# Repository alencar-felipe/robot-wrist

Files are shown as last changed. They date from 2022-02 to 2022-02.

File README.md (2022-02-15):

# robot-wrist

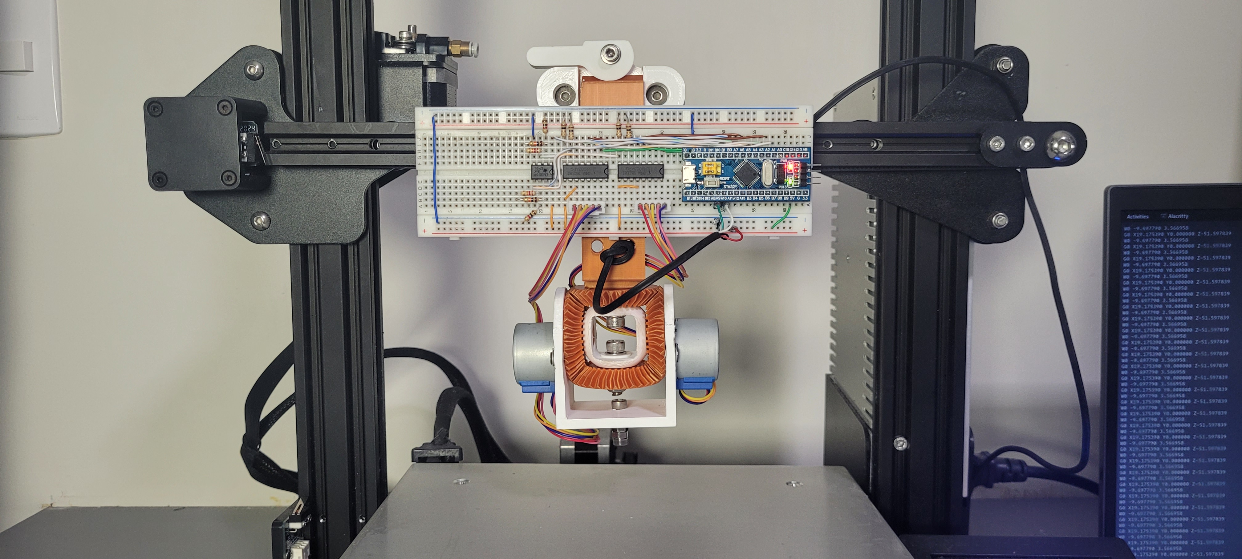
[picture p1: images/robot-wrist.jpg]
robot-wrist


## About

The robot-wrist is a robot that (tries to) mimic the movement of a human wrist
(and forearm). In addition to developing the robot itself, it also was 
integrated with a 3D printer and a PS4 controller to demonstrate a usage case.

Furthermore, it is the final project of the discipline of Microprocessed Systems
taught by Professor Ricardo Jardel Nunes da Silveira from the Federal University
of Ceará (UFC).

## Authors

- Dariel Bezerra de Sousa (495208)
- Felipe Paiva Alencar (494543).

## Summary
- [Controller](controller/)
- [Firmware](firmware/)
- [OpenSCAD (3D Model)](openscad/)
- [Proteus (Schematic)](proteus)

## Video

Video (https://www.youtube.com/watch?v=ubxL-wMxCd8 "Projeto Final da Disciplina de POO")

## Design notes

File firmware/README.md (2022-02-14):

# Firmware

## About

This firmware runs on an [STM32F103C6T6](https://www.st.com/en/microcontrollers-microprocessors/stm32f103c6.html).
The main highlight of this code is that it does not use the Hardware 
Abstraction Layer (HAL) provided by the STM32CubeMX software. Therefore, we
configured all the registers manually. (We also made the linker and startup code
from scratch)

The code listens for incoming gcode commands from the USART and, when the robot 
receives a command, it takes the necessary action: move the motors, change the
coordinate origin or measure current.

Peripherals used: ADC1, ADC2, GPIO, TIM3, USART1. 

## Custom Gcode
### W0: Move
Performs a movement.

#### Usage
```
W0 [rotation] [arm]
```

#### Parameters
- [rotation]: rotation angle in degrees
- [arm]: arm angle in degrees

#### Example
```
W0 180.0 0.0
```

### W1: Set position
Set the current position to the values specified. (Does not move the motors)

#### Usage
```
W1 [rotation] [arm]
```
#### Parameters
- [rotation]: rotation angle in degrees
- [arm]: arm angle in degrees

#### Example
```
W1 0.0 0.0
```

### W2: Get electric currents value
Gets currents of both motors in amperes.

#### Usage
```
W2
```

#### Example

```
W2
0.141 0.136
```

## Build

```
$ make clean && make build
```

## Flash

```
$ make flash
```
## Debug

```
$ openocd -f stlink_bluepill.cfg &
$ arm-none-eabi-gdb build/robot-wrist.elf
(gdb) target remote :3333
```

Reset: ```monitor reset halt```

## References

- https://www.st.com/resource/en/reference_manual/cd00171190-stm32f101xx-stm32f102xx-stm32f103xx-stm32f105xx-and-stm32f107xx-advanced-arm-based-32-bit-mcus-stmicroelec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
- https://mensi.ch/blog/articles/bare-metal-c-programming-the-blue-pill-part-1
- https://github.com/fcayci/stm32f1-bare-metal
- https://vivonomicon.com/2020/06/28/bare-metal-stm32-programming-part-10-uart-communication/
- https://stackoverflow.com/questions/22317477/setting-up-heap-in-memory-for-arm-embedded-system
- https://github.com/IDWizard/uln2003

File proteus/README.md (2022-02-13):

# Proteus

An STM32 is the main microcontroller. This MCU controls two stepper motor
drivers, which, in turn, controls two stepper motors. Furthermore, an ammeter
accompanies each motor driver.

## Material
 - 1x STM32F103C6 (MCU)
 - 2x 28BYJ-48 (Stepper Motor)
 - 2x ULN2003A (Stepper Motor Driver)
 - 1x LM358 (OP-AMP)

## Schematic

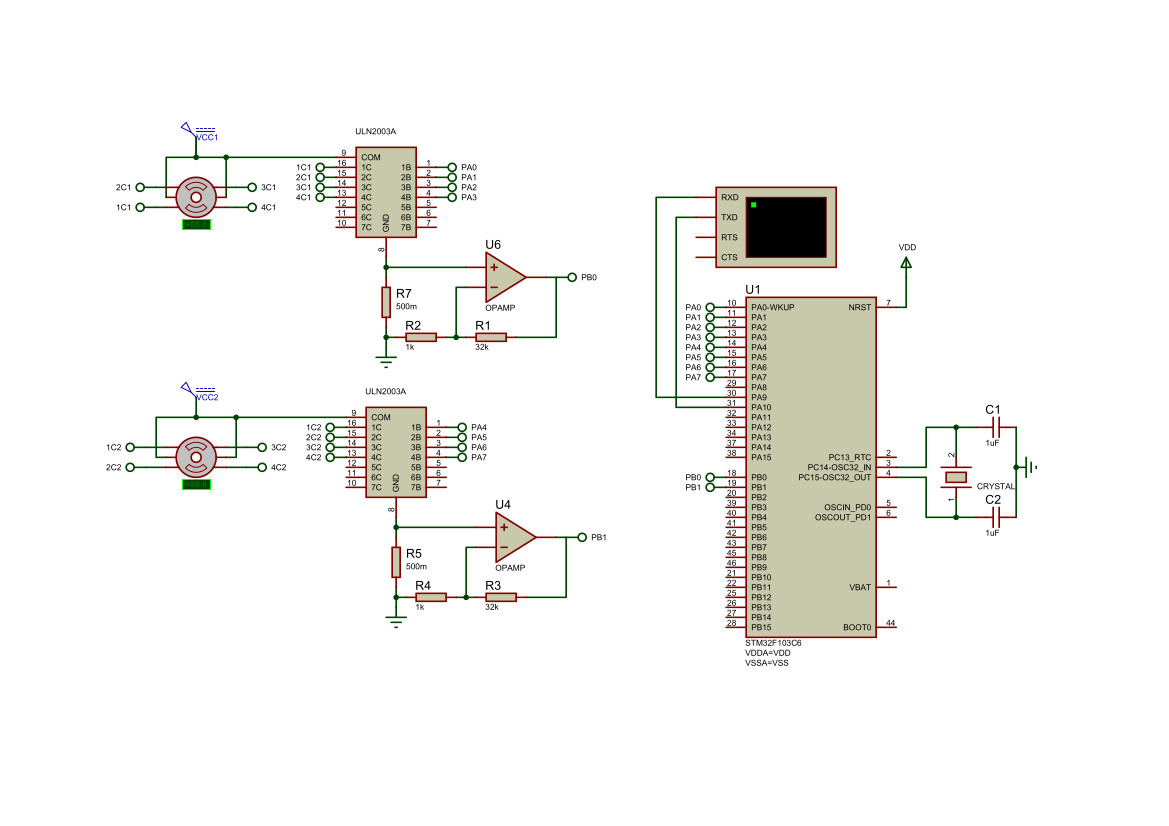
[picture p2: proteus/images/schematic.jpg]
Schematic


## Protoboard

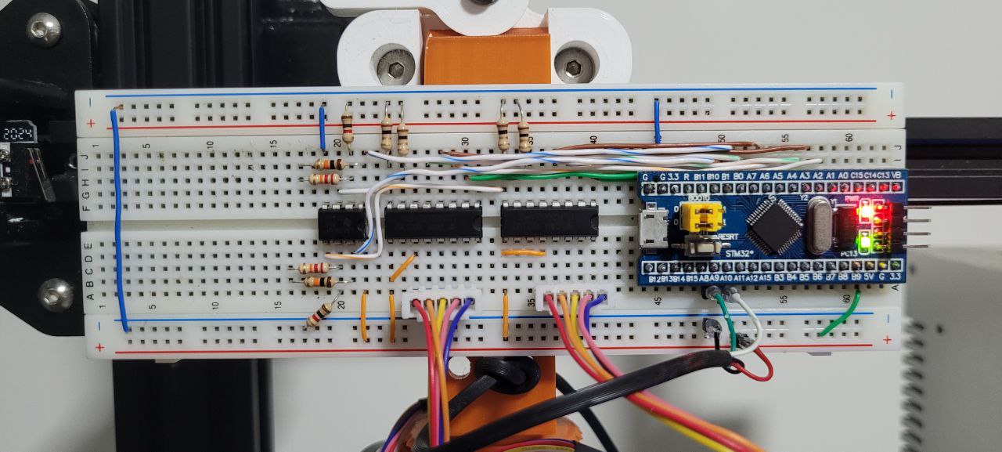
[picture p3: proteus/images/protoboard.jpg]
Protoboard


## Resources
- https://www.st.com/resource/en/datasheet/stm32f103c6.pdf
- https://www.mouser.com/datasheet/2/758/stepd-01-data-sheet-1143075.pdf
- https://www.st.com/resource/en/datasheet/uln2001.pdf
- https://www.ti.com/lit/ds/symlink/lm158-n.pdf
- https://www.filipeflop.com/wp-content/uploads/2017/07/450xN-4-2.jpg

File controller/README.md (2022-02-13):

# Controller

Simple Python script to control a 3D printer (running 
[marlin](https://marlinfw.org/meta/gcode/)) and the robot-wrist via a PS4
cotroller.

## Button Mapping

PS4 Controller

- Button 6 (L2): Printer Z axis up

- Button 7 (R2): Printer Z axis down

- Button 10 (L3):
    - X axis: Printer X axis
    - Y axis: Printer Y axis

- Button 11 (R3):
    - X axis: robot-wrist rotation
    - Y axis: robot-wrist arm

## Run

```
pip install -r requirements.txt
python3 controller.py <robot-wrist-serial-port> <marlin-serial-port>
```

## Resources
- https://marlinfw.org/meta/gcode/
- https://pypi.org/project/pyPS4Controller/
- https://forum.unity.com/proxy.php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

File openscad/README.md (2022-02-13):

# OpenSCAD

3D model for a robot that mimics the movement of a human wrist (and forearm) 
with a spur-gear differential. This 3D model, basically, is a scaled down version
of the model made by: [Tiago Charters de Azevedo](youtube.com/watch?v=JI7P6k4t3Ws)

## Render

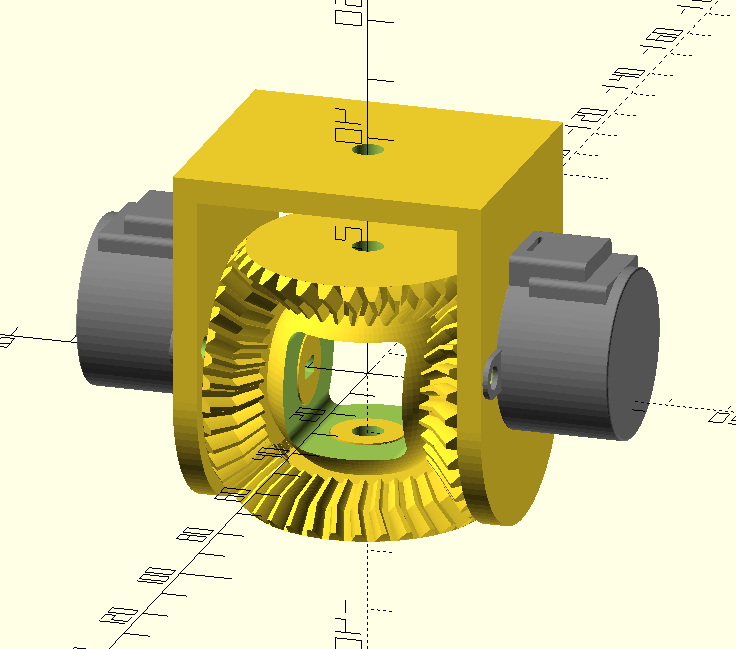
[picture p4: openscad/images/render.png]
OpenSCAD Render


[3D Visualization](robot-wrist.stl)

## 3D Printed

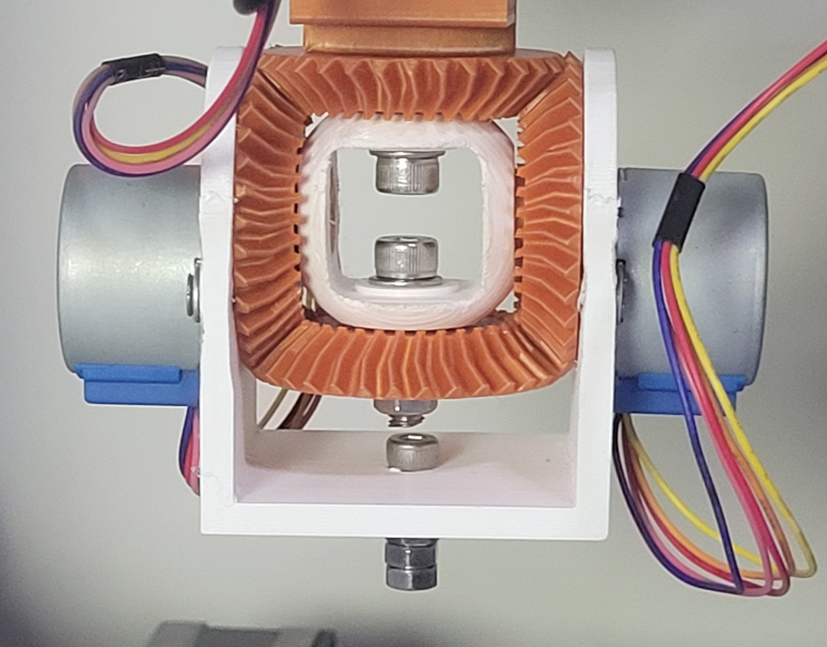
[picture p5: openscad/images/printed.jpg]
3D Printed


## Resources
- https://www.youtube.com/watch?v=JI7P6k4t3Ws
- https://www.youmagine.com/designs/improved-robot-arm-with-a-3d-printed-differential-wrist-3-25
- https://github.com/chrisspen/gears

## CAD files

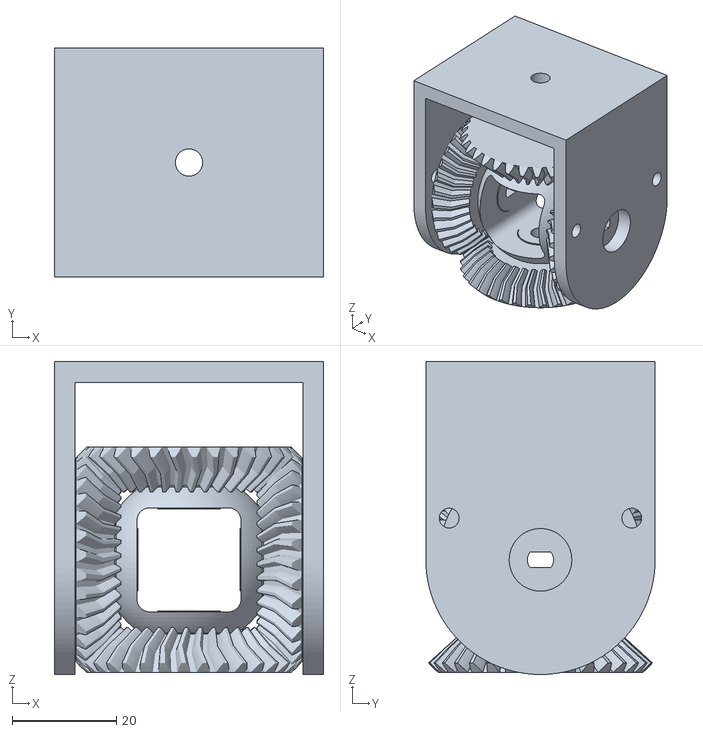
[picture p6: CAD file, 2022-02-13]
openscad/robot-wrist.stl
51.7 x 44.0 x 60.0

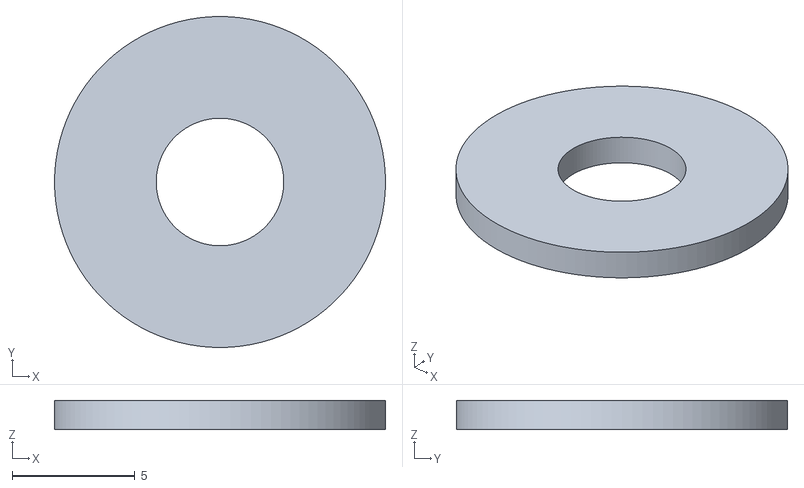
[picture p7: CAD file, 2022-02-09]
openscad/whasher.stl
13.5 x 13.5 x 1.20

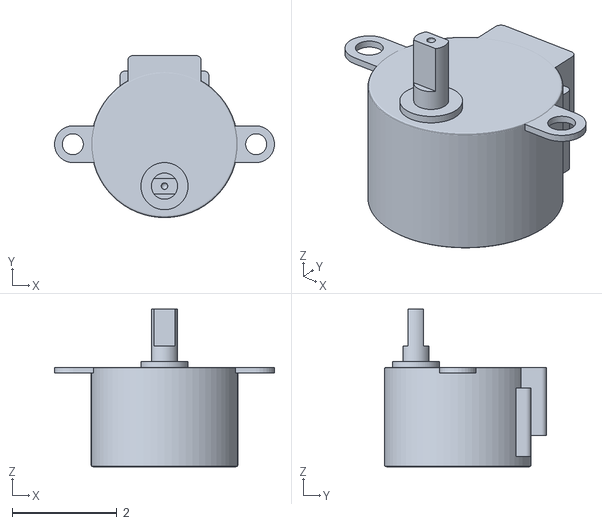
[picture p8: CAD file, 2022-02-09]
openscad/stepper.stl
4.20 x 3.10 x 3.01

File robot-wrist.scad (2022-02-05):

include <gears.scad>
include <nema17.scad>
include <../utils/threads.scad>

gear2_bolt_hex_d=12.8;
gear2_bolt_sink=4;



h=5;

modul=1.5;
top_tooth_number=53;
rt_tooth_number=top_tooth_number;
small_tooth_number=11;
a=modul*(2+top_tooth_number);

b=modul*(2+rt_tooth_number);
aa=modul*(2+small_tooth_number);

db=-aa/2+2*(modul+modul/6);

c=a;
rtube=2.54*10;
echo(c);
tol=.4;

smallgearoffset=.6;


////////////////////////////////////////////////////////////
nema=0;
module big_gear(modul=1.5){
	bevel_herringbone_gear(
	    modul=modul,
	    tooth_number=top_tooth_number,
	    partial_cone_angle=45,
	    tooth_width=10,
	    bore=4,
	    pressure_angle=20,
	    helix_angle=-20);
    }


module top_gear(modul=1.5,m=11){
    difference(){
	union(){
	    bevel_herringbone_gear(
		modul=modul,
		tooth_number=top_tooth_number,
		partial_cone_angle=45,
		tooth_width=10,
		bore=4,
		pressure_angle=20,
		helix_angle=20);

	    translate([0,0,-7]){
	    cylinder(h=(10+2*modul)*sin(45)+7,r=16,center=false);
	    cylinder(h=7,r1=a/2-2*modul-7,r2=a/2-sqrt(2)*modul,center=false);
	}
	    
    }
    
    translate([0,0,(10+2*modul)*sin(45)-7])
    poly_cylinder(h=7+.5,r=11);
    
    translate([0,0,-3.5])	
    poly_cylinder(h=7+.5,r=11,center=true);
    
    poly_cylinder(h=100,r=11-.32,center=true);


    //holes
    for(i=[0:m-1]){
	rotate([0,0,i*360/m])
	translate([0,a/3.5,0])
	poly_cylinder(h=20,r=4,center=true);}
}
}

module bottom_gear(modul=1.5,m=11){
    difference(){
	union(){
	    bevel_herringbone_gear(
		modul=modul,
		tooth_number=top_tooth_number,
		partial_cone_angle=45,
		tooth_width=10,
		bore=4,
		pressure_angle=20,
		helix_angle=20);
	    
	    translate([0,0,-7]){
		cylinder(h=(10+2*modul)*sin(45)+7,r=16,center=false);
	    }

	    translate([0,0,-7]){
	    cylinder(h=(10+2*modul)*sin(45)+7,r=16,center=false);
	    cylinder(h=7,r1=a/2-2*modul-7,r2=a/2-sqrt(2)*modul,center=false);
	}
    }
    
    translate([0,0,(10+2*modul)*sin(45)-7])
    poly_cylinder(h=7+.5,r=11);
    
    translate([0,0,-3.5])	
    poly_cylinder(h=7+.5,r=11,center=true);
    
    poly_cylinder(h=100,r=11-.32,center=true);
    
    //holes
    for(i=[0:m-1]){
	rotate([0,0,i*360/m])
	translate([0,a/3.5,0])
	poly_cylinder(h=20,r=4,center=true);}
}

height=50;
translate([0,0,-height-.01])
base(height=height,screws=true);
}

module lr_big_gear(modul=1.5,m=11){
    difference(){
	union(){
	    difference(){
		big_gear();
		translate([0,0,3.5+.4])
		poly_cylinder(h=7,r=11,center=true);
		
		poly_cylinder(h=100,r=11-.32,center=true);}
	    
	    translate([0,0,-10])
	    difference(){
		herringbone_gear(
		    modul=modul,
		    tooth_number=rt_tooth_number,
		    width=10,
		    bore=2*(11-.32),
		    pressure_angle=20,
		    helix_angle=30,
		    optimized=false);
		
		translate([0,0,3.5])
		poly_cylinder(h=7,r=11,center=true);}}

        //holes
    for(i=[0:m-1]){
	rotate([0,0,i*360/m])
	translate([0,a/3.5,0])
	poly_cylinder(h=20,r=4,center=true);}
}
}

module small_gear(modul=1.5){
    translate([0,a/2+smallgearoffset,-7]){
	rotate([0,0,-9])
	union(){
	    herringbone_gear(
		modul=modul,
		tooth_number=small_tooth_number,
		width=10,
		bore=5,
		pressure_angle=20,
		helix_angle=-30,
		optimized=false);
	}
	
	translate([0,0,-10])
	difference(){
	    cylinder(h=10,r=aa/2);
	    poly_cylinder(h=20,r=2.5,center=true);
	    
	    translate([0,0,5])
	    rotate([0,90,0])
	    poly_cylinder(h=20,r=1.5,center=true);
	    
	    translate([-5,0,5])
	    cube([2.8,5.6,10+.1],center=true);
	}
    }
	
}



module show(){
    translate([0,0,a/2])
    rotate([0,180,0])
    top_gear(modul=modul);
    
    translate([-a/2,0,0])
    rotate([0,90,0])
    lr_big_gear();
    
    union(){
	translate([a/2,0,0])
	rotate([0,-90,])
	lr_big_gear();
	
	translate([a/2+3,0,db])
	rotate([-90+0,0,0])
	rotate([0,-90,0])
	small_gear();}
    
    middleU();
    
    translate([-a/2-10*cos(45)-10-1.6,0,0]) lateral();
    
    translate([-a/2-3,0,db])
    rotate([-90,0,180])
    rotate([0,-90,0])
    small_gear(modul);
    
    
    translate([a/2+10*cos(45)+10+1.6,0,0])    rotate([0,0,180])    lateral();

    if(nema==1){
	// NEMA
	translate([-a/2-20-7,0,-a/2+db])
	rotate([0,90,0])
	nema17();
	
	// NEMA
	rotate([0,0,180])
	translate([-a/2-20-7,0,-a/2+db])
	rotate([0,90,0])
	nema17();}
	
	translate([0,0,a/2+25])    arm1(height=50-15);

    translate([0,0,-a/2])
    bottom_gear(modul=modul);

//    translate([0,0,a/2+200])
//    nema17();
}

show();
    


module middleU(c=a-10/sin(45)-2*1.6){
    rsphere=.65*c;
    lcube=c-4*7-1;
    difference(){
	intersection(){
	    cube(c*[1,1,1],center=true);
	    sphere(r=rsphere);}
	
	cube([lcube,100,lcube],center=true);
	
	poly_cylinder(h=100,r=11-.32,center=true);
	rotate([0,90,0])
	poly_cylinder(h=100,r=11-.32,center=true);

	// bearing hole
	for(i=[0:3]){
	    rotate([0,360*i/4,0]){
		    translate([0,0,c/2-3]) 
		    poly_cylinder(h=8,r=11,center=true);
		    translate([0,0,c/2-2*7+2])
		    poly_cylinder(h=8,r=11,center=true);}}}
    
    intersection(){
	sphere(r=rsphere);
	union(){
	    translate([lcube/2,0,lcube/2])
	    difference(){
		rotate([0,90,90])
		cylinder(h=c,r=7/2,center=true);
		translate([-7/2,0,-7/2])
		rotate([0,90,90])
		cylinder(h=c+1,r=7/2,center=true);}
	    
	    translate([-lcube/2,0,lcube/2])
	    difference(){
		rotate([0,90,90])
		cylinder(h=c,r=7/2,center=true);
		translate([7/2,0,-7/2])
		rotate([0,90,90])
		cylinder(h=c+1,r=7/2,center=true);}

	    ////////////////////////////////////////////////////////////
	    
	    translate([-lcube/2,0,-lcube/2])
	    difference(){
		rotate([0,90,90])
		cylinder(h=c,r=7/2,center=true);
		translate([7/2,0,7/2])
		rotate([0,90,90])
		cylinder(h=c+1,r=7/2,center=true);}

	    translate([lcube/2,0,-lcube/2])
	    difference(){
		rotate([0,90,90])
		cylinder(h=c,r=7/2,center=true);
		
		translate([-7/2,0,7/2])
		rotate([0,90,90])
		cylinder(h=c+1,r=7/2,center=true);}
	    
	    
	}}
}


module base(radius=a/2-modul,height=110, screws=false){
//    height=110;
    difference(){
	union(){
	    cylinder(h=height,r=radius+h,center=false);

	    cylinder(h=10,r=radius+3*h,center=false);

	    translate([0,0,-h])
	    cylinder(h=h,r=radius+3*h+.5*h,center=false);
	}
	poly_cylinder(h=10*height,r=radius,center=true);    
    
	wheel_radius = radius+5*h;
	tyre_diameter = 4*h;
	
	translate([0,0,2*h])
	rotate_extrude(angle=360) {
	    translate([wheel_radius - tyre_diameter/2, 0])
            circle(d=tyre_diameter);}

	if (screws){
	    for(i=[0:6]){
		rotate([0,0,i*360/7])
		translate([0,radius+2.5*h,0]){
		    poly_cylinder(h=100,r=1.5,center=true);
		    translate([0,0,0])
		    poly_cylinder(h=h,r=4,center=true);}}}


    // for(i=[0:6]){
    // 	rotate([0,0,(i+1/4)*360/7])
    // 	translate([0,0,height/1.25]){
    // 	    rotate([0,90,0])
    // 	    poly_cylinder(h=rtube+2*h,r=1.5,center=false);}}

}}

module lateral(width=15){
    lm3=31/2;
    l=105;
    difference(){
	union(){
	    hull(){
		rotate([0,90,0])
		cylinder(h=width,r=a/2,center=true);

		translate([0,0,a/2+15])
		cube([width,a,.01],center=true);

		translate([0,0,-b/2+db])
		rotate([0,90,0])

		minkowski(){
		    cube([43.3-5,43.3-5,width/2],center=true);
		    cylinder(h=width/2,r=2.5,center=true);}
	    }

	}

//	translate([0,-a/4,a/2+10]) cube([a/1.5,14.5,1],center=true);
	
	translate([0,a/4,a/2]) cube([a/1.5,15,6.3],center=true);
	translate([0,-a/4,a/2]) cube([a/1.5,15,6.3],center=true);

	translate([0,a/4,a/2])
	poly_cylinder(h=50,r=4,center=true);
	translate([0,-a/4,a/2])
	poly_cylinder(h=50,r=4,center=true);

	translate([h+.01,0,-smallgearoffset]){
	    ////////////////////////////////////////////////////////////
	    translate([0,0,-b/2+db])
	    rotate([0,90,0]){
		translate([lm3,lm3,0])
		poly_cylinder(h=h,r=4,center=true);
		translate([-lm3,lm3,0])
		poly_cylinder(h=h,r=4,center=true);
		translate([lm3,-lm3,0])
		poly_cylinder(h=h,r=4,center=true);
		translate([-lm3,-lm3,0])
		poly_cylinder(h=h,r=4,center=true);
		// Big hole

		poly_cylinder(h=15,r=23/2+6-.8,center=true);}
	    
	    translate([0,0,-b/2+db-20])
	    cube([width,20,width],center=true);
	    ////////////////////////////////////////////////////////////
	
	translate([0,0,-b/2+db])
	rotate([0,90,0]){
	    translate([lm3,lm3,0])
	    poly_cylinder(h=2*l,r=1.5,center=true);
	    translate([-lm3,lm3,0])
	    poly_cylinder(h=2*l,r=1.5,center=true);
	    translate([lm3,-lm3,0])
	    poly_cylinder(h=2*l,r=1.5,center=true);
	    translate([-lm3,-lm3,0])
	    poly_cylinder(h=2*l,r=1.5,center=true);
	    // Big hole    
	    poly_cylinder(h=2*l,r=23/2,center=true);}}

	rotate([0,90,0])
	poly_cylinder(h=2*l,r=4,center=true);

	translate([gear2_bolt_sink,0,0])
	rotate([0,90,0])
	cylinder(r=.5*gear2_bolt_hex_d /cos(180/6),h=gear2_bolt_sink,$fn=6);



}

}

module arm1(height=165){
    lenght=a/2+10*cos(45)+10+1.6+7.5;
    echo(lenght);
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

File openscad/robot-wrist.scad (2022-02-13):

include <gears.scad>

$fn=100;

thk=4;
nop=0.01;
screw=5.2;
bear=12; //bearing horizontal
bear_c=0.2; //bearing clearance
arm_c=0.2; //arm clearance
insert=3.8;
stteper_hole=12;

// HELPERS =====================================//

module rounded_square(s, r) {
    k = s/2 - r;
    
	hull() {
		translate([k, k, 0])
        circle(r);
		translate([k, -k, 0])
        circle(r);
		translate([-k, -k, 0])
        circle(r);
		translate([-k, k, 0])
        circle(r);
	}
}

module half_cylinder(h, d) {
    intersection() {
        cylinder(h=h, d=d, center=true);
        translate([0, d/4, 0])
        cube([d, d/2, h], center=true);
    }
}

module axis(h, d, c) {
   intersection() {
        cylinder(h=h, d=d);
        cube([c, d, 2*h], center=true);
    }
} 

// STEPPER =====================================//

module stepper() {
    translate([0, 8, -19/2])
    scale(10)
    import("stepper.stl", convexity=3);
}

module steppers(dx) {
    color("grey")
    for(i = [-1, 1]) {
        translate([i*dx, 0, 0])
        rotate([90, 0, -i*90])
        stepper();
    }
}

// DICE ========================================//

module dice(in, out, d, f, bore) {
    difference() {
        intersection() {
            cube(out, center=true);
            sphere(d=d);
        }
        
        rotate([90, 0, 0])
        linear_extrude(out+nop, center=true)
        rounded_square(in, f);
        
        cylinder(out+nop, d=bore,
        center=true);
        
        rotate([0, 90, 0])
        cylinder(out+nop, d=bore,
        center=true);
    }
}

// ARM =========================================//

module arm(size, gear_x) {
    dx = (gear_x + thk/2 + arm_c);
    side_h = sqrt(pow(gear_x+10, 2) + pow(10/2, 2))+2;
   
    for(i = [-1, 1]) {
        translate([i*dx, 0, 0]) {
            difference() {
                union() {
                    rotate([-90, 0, 90])
                    half_cylinder(thk, size);
                    translate([0, 0, side_h/2])
                    cube([thk, size, side_h+nop],
                        center=true);
                }
                
                for(j = [-1, 1])
                translate([0, j*35/2, 8])
                rotate([0, 90, 0])
                cylinder(h=thk+nop, d=insert, center=true);
                
                rotate([0, 90, 0])
                cylinder(h=thk+nop, d=stteper_hole, 
                    center=true);
            }
            
        }
    }
    
    translate([0, 0, thk/2+side_h])
    difference() {
        cube([2*dx+thk, size, thk], center=true); 
        cylinder(h=thk+nop, d=screw, center=true);
    }
}

// GEARS =======================================//

module differential(){
    modul = 1.25;
    teeth = 33;
    tooth_width = 10;
    pressure_angle = 20;
    helix_angle = 10;
    clearance = 0.05;

    
    // Math from bevel_herringbone_gear_pair()
    r = modul*teeth/2;
    rg = r/sin(45);
    c = modul / 6;   
    df = pi*rg/2 - 2 * (modul + c);    
    rf = df / 2;            
    delta_f = rf/(pi*rg) * 180; 
    height_f = rg*cos(delta_f);               
    height_k = (rg-tooth_width)/cos(45);      
    rk = (rg-tooth_width)/sin(45);   
    height_fk = rk*height_k/(height_k*tan(delta_f)+rk); 
    height  = height_f-height_fk;
    ro = rg + 2*height/tan(45);
    
    rot = 180*(1-clearance)/teeth*is_even(teeth);
    
    dice_out = 2*height_fk - 0.5;
    dice_in = dice_out-2*thk;
    
    module gear(comp) {
        tmp = (comp) ? -1 : 1;
        
        union() {
            bevel_herringbone_gear(
                modul=modul,
                tooth_number=teeth,
                partial_cone_angle=45,
                tooth_width=tooth_width,
                bore=screw,
                pressure_angle=pressure_angle,
                helix_angle=tmp*helix_angle);
            
             cylinder(h=height_f-dice_in/2+bear_c, d=bear);
        }
    }
    
    for(i = [-1, 1])
    rotate([0,0,rot]) 
    translate([0, 0, i*height_f])
    rotate([0, (i+1)*90, 0])
    difference() {
        gear(false);
        translate([0, 0, -nop])
        cylinder(h=height_f-dice_in/2+bear_c+2*nop, d=screw);
    }
     
    for(i = [-1, 1])
    translate([i*height_f, 0, 0])
    rotate([0, -i*90, 0]) 
    difference() {
        gear(true);   
        axis(height_f, 5, 3);
    }
    
    dice(out=dice_out, in=dice_out-2*thk,
    d=1.2*dice_out, f=2.5, bore=bear+2*bear_c);
    
    arm(size=ro, gear_x=height_f);
    
    if($preview) {
        steppers(dx=height_f+thk);
    }
    
    echo("dice_in = ", dice_in);
}

differential();

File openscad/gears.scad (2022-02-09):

$fn = 50;

/* Library for Involute Gears, Screws and Racks

This library contains the following modules
- rack(modul, length, height, width, pressure_angle=20, helix_angle=0)
- mountable_rack(modul, length, height, width, pressure_angle=20, helix_angle=0, fastners, profile, head)
- herringbone_rack(modul, length, height, width, pressure_angle = 20, helix_angle=45)
- mountable_herringbone_rack(modul, length, height, width, pressure_angle=20, helix_angle=45, fastners, profile, head)
- spur_gear(modul, tooth_number, width, bore, pressure_angle=20, helix_angle=0, optimized=true)
- herringbone_gear(modul, tooth_number, width, bore, pressure_angle=20, helix_angle=0, optimized=true)
- rack_and_pinion (modul, rack_length, gear_teeth, rack_height, gear_bore, width, pressure_angle=20, helix_angle=0, together_built=true, optimized=true)
- ring_gear(modul, tooth_number, width, rim_width, pressure_angle=20, helix_angle=0)
- herringbone_ring_gear(modul, tooth_number, width, rim_width, pressure_angle=20, helix_angle=0)
- planetary_gear(modul, sun_teeth, planet_teeth, number_planets, width, rim_width, bore, pressure_angle=20, helix_angle=0, together_built=true, optimized=true)
- bevel_gear(modul, tooth_number,  partial_cone_angle, tooth_width, bore, pressure_angle=20, helix_angle=0)
- bevel_herringbone_gear(modul, tooth_number, partial_cone_angle, tooth_width, bore, pressure_angle=20, helix_angle=0)
- bevel_gear_pair(modul, gear_teeth, pinion_teeth, axis_angle=90, tooth_width, bore, pressure_angle = 20, helix_angle=0, together_built=true)
- bevel_herringbone_gear_pair(modul, gear_teeth, pinion_teeth, axis_angle=90, tooth_width, bore, pressure_angle = 20, helix_angle=0, together_built=true)
- worm(modul, thread_starts, length, bore, pressure_angle=20, lead_angle=10, together_built=true)
- worm_gear(modul, tooth_number, thread_starts, width, length, worm_bore, gear_bore, pressure_angle=20, lead_angle=0, optimized=true, together_built=true)

Examples of each module are commented out at the end of this file

Author:     Dr Jörg Janssen
Contributions By:   Keith Emery, Chris Spencer
Last Verified On:      1. June 2018
Version:    2.2
License:     Creative Commons - Attribution, Non Commercial, Share Alike

Permitted modules according to DIN 780:
0.05 0.06 0.08 0.10 0.12 0.16
0.20 0.25 0.3  0.4  0.5  0.6
0.7  0.8  0.9  1    1.25 1.5
2    2.5  3    4    5    6
8    10   12   16   20   25
32   40   50   60

*/


// General Variables
pi = 3.14159;
rad = 57.29578;
clearance = 0.05;   // clearance between teeth

/*  Converts Radians to Degrees */
function grad(pressure_angle) = pressure_angle*rad;

/*  Converts Degrees to Radians */
function radian(pressure_angle) = pressure_angle/rad;

/*  Converts 2D Polar Coordinates to Cartesian
    Format: radius, phi; phi = Angle to x-Axis on xy-Plane */
function polar_to_cartesian(polvect) = [
    polvect[0]*cos(polvect[1]),
    polvect[0]*sin(polvect[1])
];

/*  Circle Involutes-Function:
    Returns the Polar Coordinates of an Involute Circle
    r = Radius of the Base Circle
    rho = Rolling-angle in Degrees */
function ev(r,rho) = [
    r/cos(rho),
    grad(tan(rho)-radian(rho))
];

/*  Sphere-Involutes-Function
    Returns the Azimuth Angle of an Involute Sphere
    theta0 = Polar Angle of the Cone, where the Cutting Edge of the Large Sphere unrolls the Involute
    theta = Polar Angle for which the Azimuth Angle of the Involute is to be calculated */
function sphere_ev(theta0,theta) = 1/sin(theta0)*acos(cos(theta)/cos(theta0))-acos(tan(theta0)/tan(theta));

/*  Converts Spherical Coordinates to Cartesian
    Format: radius, theta, phi; theta = Angle to z-Axis, phi = Angle to x-Axis on xy-Plane */
function sphere_to_cartesian(vect) = [
    vect[0]*sin(vect[1])*cos(vect[2]),
    vect[0]*sin(vect[1])*sin(vect[2]),
    vect[0]*cos(vect[1])
];

/*  Check if a Number is even
    = 1, if so
    = 0, if the Number is not even */
function is_even(number) =
    (number == floor(number/2)*2) ? 1 : 0;

/*  greatest common Divisor
    according to Euclidean Algorithm.
    Sorting: a must be greater than b */
function ggt(a,b) =
    a%b == 0 ? b : ggt(b,a%b);

/*  Polar function with polar angle and two variables */
function spiral(a, r0, phi) =
    a*phi + r0;

/*  Copy and rotate a Body */
module copier(vect, number, distance, winkel){
    for(i = [0:number-1]){
        translate(v=vect*distance*i)
            rotate(a=i*winkel, v = [0,0,1])
                children(0);
    }
}

/*  rack
    modul = Height of the Tooth Tip above the Rolling LIne
    length = Length of the Rack
    height = Height of the Rack to the Pitch Line
    width = Width of a Tooth
    pressure_angle = Pressure Angle, Standard = 20° according to DIN 867. Should not exceed 45°.
    helix_angle = Helix Angle of the Rack Transverse Axis; 0° = Spur Teeth */
module rack(modul, length, height, width, pressure_angle = 20, helix_angle = 0) {

    // Dimension Calculations
    modul=modul*(1-clearance);
    c = modul / 6;                                              // Tip Clearance
    mx = modul/cos(helix_angle);                          // Module Shift by Helix Angle in the X-Direction
    a = 2*mx*tan(pressure_angle)+c*tan(pressure_angle);       // Flank Width
    b = pi*mx/2-2*mx*tan(pressure_angle);                      // Tip Width
    x = width*tan(helix_angle);                          // Topside Shift by Helix Angle in the X-Direction
    nz = ceil((length+abs(2*x))/(pi*mx));                       // Number of Teeth

    translate([-pi*mx*(nz-1)/2-a-b/2,-modul,0]){
        intersection(){                                         // Creates a Prism that fits into a Geometric Box
            copier([1,0,0], nz, pi*mx, 0){
                polyhedron(
                    points=[[0,-c,0], [a,2*modul,0], [a+b,2*modul,0], [2*a+b,-c,0], [pi*mx,-c,0], [pi*mx,modul-height,0], [0,modul-height,0], // Underside
                        [0+x,-c,width], [a+x,2*modul,width], [a+b+x,2*modul,width], [2*a+b+x,-c,width], [pi*mx+x,-c,width], [pi*mx+x,modul-height,width], [0+x,modul-height,width]],   // Topside
                    faces=[[6,5,4,3,2,1,0],                     // Underside
                        [1,8,7,0],
                        [9,8,1,2],
                        [10,9,2,3],
                        [11,10,3,4],
                        [12,11,4,5],
                        [13,12,5,6],
                        [7,13,6,0],
                        [7,8,9,10,11,12,13],                    // Topside
                    ]
                );
            };
            translate([abs(x),-height+modul-0.5,-0.5]){
                cube([length,height+modul+1,width+1]);          // Cuboid which includes the Volume of the Rack
            }
        };
    };
}

/* Mountable-rack; uses module "rack"
    modul = Height of the Tooth Tip above the Rolling LIne
    length = Length of the Rack
    height = Height of the Rack to the Pitch Line
    width = Width of a Tooth
    pressure_angle = Pressure Angle, Standard = 20° according to DIN 867. Should not exceed 45°.
    helix_angle = Helix Angle of the Rack Transverse Axis; 0° = Spur Teeth
    fastners = Total number of fastners.
    profile = Metric standard profile for fastners (ISO machine screws), M4 = 4, M6 = 6 etc.
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

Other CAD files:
gears.scad

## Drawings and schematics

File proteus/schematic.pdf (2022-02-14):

# 9 GND 8

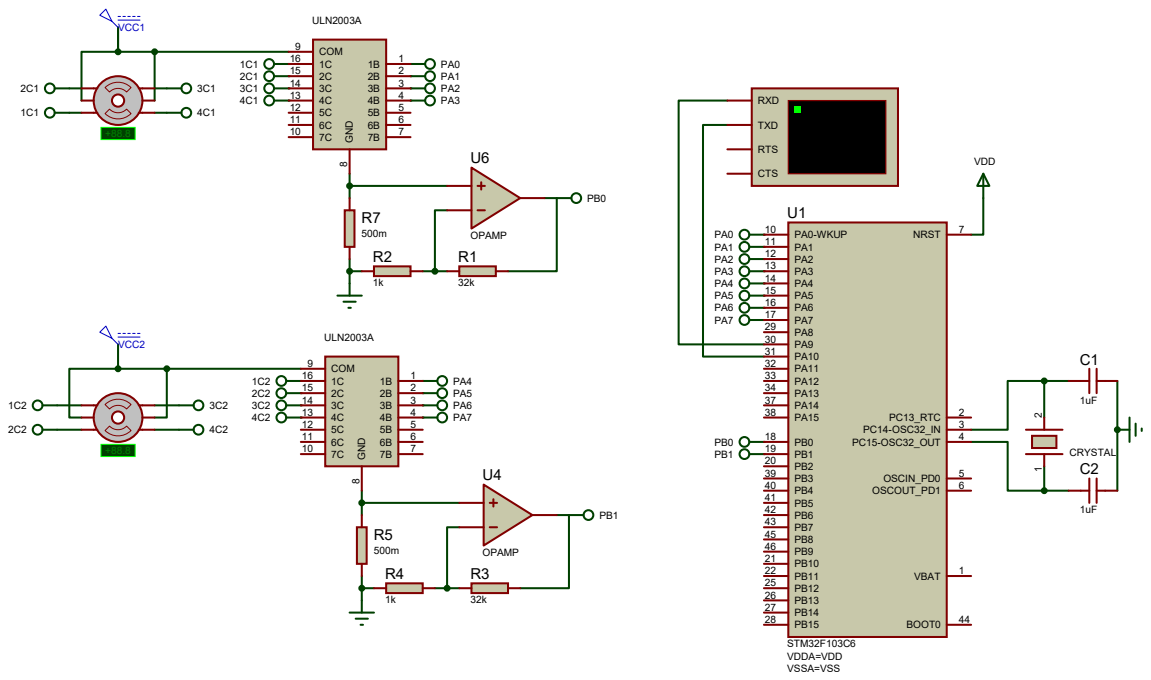
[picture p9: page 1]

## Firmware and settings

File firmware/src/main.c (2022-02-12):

#include "main.h"

#define STEPS_PER_REV (4096)
#define OPAMP_GAIN (33.0)
#define SHUNT (0.5) //ohm
#define BUFLEN (1024)

stepper_t stepper1; //stepper 1
stepper_t stepper2; //stepper 2
int ret; //return value for stdlib functions
char gcode_char; //gcode command char
int cmd; //gcode command
float rot; //for sscanf
float arm; //for sscanf
float cur_rot = 0; //current rotation position
float cur_arm = 0; //current arm position
float sens1 = 0; //motor 1 current
float sens2 = 0; //motor 2 current
char buf[BUFLEN]; //fgets buffer

void clock_setup();
void gpios_setup();
void steppers_setup();
void timer_setup();
void current_sense();
void move();
void tim3_handler();
void wait();
void enable_interrupt(IRQn_Type IRQn);
void disable_interrupt(IRQn_Type IRQn);

int main() {
    clock_setup();
	gpios_setup();
	steppers_setup();
	timer_setup();
    usart_setup();
	adc_setup();

	// just to know that the program is running
	printf("robot-wrist\r\n");

    while (1) {
		// blink built-in LED
		gpio_toggle(GPIOC, 13);
		
		// read line from usart
		fgets(buf, BUFLEN, stdin);

		// decode gcode
		ret = sscanf(buf, " %c%d %f %f", &gcode_char, &cmd, &rot, &arm);
		
		if(gcode_char != 'W' || ret < 2) cmd = -1;

		switch(cmd) {
			case 0: //move
				if(ret == 4) {
					move();
					continue;
				}
				
			case 1: //set position
				if(ret == 4) {
					cur_rot = rot;
					cur_arm = arm;
					continue;
				}

			case 2: //current sense
				if(ret == 2) {
					printf("%.3f %.3f\r\n", sens1, sens2);
					continue;	
				}
		}

		printf("Error.\r\n");
    }

	return 0;
}

void clock_setup(void)
{
	// Necessary wait states for Flash for high speeds
	FLASH->ACR = 0x12;
	// Enable HSE
	RCC->CR |= (1 << 16);
	// Wait untill HSE settles down
	while (!(RCC->CR & (1 << 17)));
	// Select Prediv1 as PLL source
	RCC->CFGR |= (1 << 16);
	// Set PLL1 multiplication factor to 9
	RCC->CFGR |= (0b0111 << 18);
	// Set APB1 to 36MHz
	RCC->CFGR |= 1 << 10;
	// Enable PLL
	RCC->CR |= (1 << 24);
	// Wait untill PLL settles down
	while (!(RCC->CR & (1 << 25)));
	// Finally, choose PLL as the system clock
	RCC->CFGR |= (0b10 << 0);
}

void gpios_setup()
{
	// built-in led
	gpio_setup(GPIOC, GPIO_OUT, 13);

	// stepper drivers
	for(uint8_t i = 0; i <= 7; i++) {
		gpio_setup(GPIOA, GPIO_OUT, i);	
	}
}

void steppers_setup()
{
	GPIO_TypeDef *gpio_ports[4];
    uint32_t gpio_pins[4];

	for(int i = 0; i < 4; i++) {
		gpio_ports[i] = GPIOA;
		gpio_pins[i] = i;
	}

	stepper_setup(&stepper1, gpio_ports, gpio_pins);

	for(int i = 0; i < 4; i++) {
		gpio_ports[i] = GPIOA;
		gpio_pins[i] = i + 4;
	}

	stepper_setup(&stepper2, gpio_ports, gpio_pins);
}

void timer_setup()
{
	// Enable clock for that module for TIM3. Bit1 in RCC APB1ENR register
	RCC->APB1ENR |= RCC_APB1ENR_TIM3EN;
	// Reset CR1 just in case
	TIM3->CR1 = 0x0000;
	// fCK_PSC / (PSC[15:0] + 1)
	// 72 Mhz / (719 + 1) = 100 khz timer clock speed
	TIM3->PSC = 719;
	// Should generate 2 ms interrupts
	TIM3->ARR = 200;
	// Update Interrupt Enable
	TIM3->DIER |= TIM_DIER_UIE;
	// Priority level 1
	NVIC->IPR[TIM3_IRQn] = 0x10;
	// Enable TIM3 from NVIC register
	enable_interrupt(TIM3_IRQn);
	// Finally enable TIM3 module
	TIM3->CR1 |= TIM_CR1_CEN;
}

void current_sense() 
{
	uint16_t raw1, raw2;
	float tmp1, tmp2;

	// Get raw ADC reading
	raw1 = adc_read(ADC1);
	raw2 = adc_read(ADC2);

	//Conversion to Amperes
	tmp1 = ((float) raw1)*(3.3 / (4095.0 * OPAMP_GAIN * SHUNT)); 
	tmp2 = ((float) raw2)*(3.3 / (4095.0 * OPAMP_GAIN * SHUNT)); 

	//Low pass filter
	sens1 = (tmp1 + 4*sens1)/5;
	sens2 = (tmp2 + 4*sens2)/5;
}

void move()
{
	int steps1, steps2;
	int rot_steps, arm_steps;
	float tmp;

	// Transform absolute angles to relative
	tmp = rot;
	rot -= cur_rot;
	cur_rot = tmp;
	tmp = arm;
	arm -= cur_arm;
	cur_arm = tmp;
	
	// Convert to motor steps
	rot_steps = rot * STEPS_PER_REV / 360.0;
	arm_steps = arm * STEPS_PER_REV / 360.0;

	// Calculate steps for each motor
	steps1 = arm_steps + rot_steps;
	steps2 = arm_steps - rot_steps;

	// Move motors
	stepper_step(&stepper1, steps1);
	stepper_step(&stepper2, -steps2);
}

void tim3_handler()
{
	current_sense();
	stepper_update(&stepper1);
	stepper_update(&stepper2);
	TIM3->SR &= ~TIM_SR_UIF;
}

void wait() 
{
    // Do some NOPs for a while to pass some time.
    for (unsigned int i = 0; i < 200000; ++i) __asm__ volatile ("nop");
}

void enable_interrupt(IRQn_Type IRQn)
{
	NVIC->ISER[((uint32_t)(IRQn) >> 5)] = (1 << ((uint32_t)(IRQn) & 0x1F));
}

void disable_interrupt(IRQn_Type IRQn)
{
	NVIC->ICER[((uint32_t)(IRQn) >> 5)] = (1 << ((uint32_t)(IRQn) & 0x1F));
}

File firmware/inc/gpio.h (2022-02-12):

#ifndef __GPIO_H
#define __GPIO_H

#include "stm32f103x6.h"

typedef enum
{
    GPIO_ANALOG = 0b0000,           //analog mode
    GPIO_INPUT = 0b0100,            //floating input (reset state) 
    GPIO_INPUT_PULL = 0b1000,       //input pull-up/pull-down
    GPIO_OUT = 0b0011,              //output push-pull
    GPIO_OUT_ODRAIN = 0b0111,       //output open-drain
    GPIO_ALT = 0b1011,              //alternate push-pull
    GPIO_ALT_ODRAIN = 0b1111        //alternate open-drain
} gpio_config_t;

typedef enum
{
    LOW = 0,
    HIGH = 1
} gpio_value_t;

void gpio_setup(GPIO_TypeDef *gpio, gpio_config_t mode, uint32_t pin);
void gpio_write(GPIO_TypeDef *gpio, uint32_t pin, gpio_value_t value);
void gpio_toggle(GPIO_TypeDef *gpio, uint32_t pin);

#endif

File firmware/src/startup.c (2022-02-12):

#include "startup.h"

// Symbols defined in the linker script
extern unsigned long _eram;
extern char _etext, _sdata, _edata, _sbss, _ebss;

// Interrupt vectors
uint32_t (* const vector_table[])
__attribute__ ((section(".interrupt_vectors"))) = {
	(uint32_t *) &_eram,             /* 0x000 Stack Pointer                   */
	(uint32_t *) reset_handler,      /* 0x004 Reset                           */
	0,                               /* 0x008 Non maskable interrupt          */
	0,                               /* 0x00C HardFault                       */
	0,                               /* 0x010 Memory Management               */
	0,                               /* 0x014 BusFault                        */
	0,                               /* 0x018 UsageFault                      */
	0,                               /* 0x01C Reserved                        */
	0,                               /* 0x020 Reserved                        */
	0,                               /* 0x024 Reserved                        */
	0,                               /* 0x028 Reserved                        */
	0,                               /* 0x02C System service call             */
	0,                               /* 0x030 Debug Monitor                   */
	0,                               /* 0x034 Reserved                        */
	0,                               /* 0x038 PendSV                          */
	0,                               /* 0x03C System tick timer               */
	0,                               /* 0x040 Window watchdog                 */
	0,                               /* 0x044 PVD through EXTI Line detection */
	0,                               /* 0x048 Tamper                          */
	0,                               /* 0x04C RTC global                      */
	0,                               /* 0x050 FLASH global                    */
	0,                               /* 0x054 RCC global                      */
	0,                               /* 0x058 EXTI Line0                      */
	0,                               /* 0x05C EXTI Line1                      */
	0,                               /* 0x060 EXTI Line2                      */
	0,                               /* 0x064 EXTI Line3                      */
	0,                               /* 0x068 EXTI Line4                      */
	0,                               /* 0x06C DMA1_Ch1                        */
	0,                               /* 0x070 DMA1_Ch2                        */
	0,                               /* 0x074 DMA1_Ch3                        */
	0,                               /* 0x078 DMA1_Ch4                        */
	0,                               /* 0x07C DMA1_Ch5                        */
	0,                               /* 0x080 DMA1_Ch6                        */
	0,                               /* 0x084 DMA1_Ch7                        */
	0,                               /* 0x088 ADC1 and ADC2 global            */
	0,                               /* 0x08C CAN1_TX                         */
	0,                               /* 0x090 CAN1_RX0                        */
	0,                               /* 0x094 CAN1_RX1                        */
	0,                               /* 0x098 CAN1_SCE                        */
	0,                               /* 0x09C EXTI Lines 9:5                  */
	0,                               /* 0x0A0 TIM1 Break                      */
	0,                               /* 0x0A4 TIM1 Update                     */
	0,                               /* 0x0A8 TIM1 Trigger and Communication  */
	0,                               /* 0x0AC TIM1 Capture Compare            */
	0,                               /* 0x0B0 TIM2                            */
	(uint32_t *) tim3_handler,       /* 0x0B4 TIM3                            */
	0,                               /* 0x0B8 TIM4                            */
	0,                               /* 0x0BC I2C1 event                      */
	0,                               /* 0x0C0 I2C1 error                      */
	0,                               /* 0x0C4 I2C2 event                      */
	0,                               /* 0x0C8 I2C2 error                      */
	0,                               /* 0x0CC SPI1                            */
	0,                               /* 0x0D0 SPI2                            */
	0,                               /* 0x0D4 USART1                          */
	0,                               /* 0x0D8 USART2                          */
	0,                               /* 0x0DC USART3                          */
	0,                               /* 0x0E0 EXTI15_10                       */
	0,                               /* 0x0E4 RTCAlarm                        */
	0,                               /* 0x0E8 USBWakeup                       */
	0,                               /* 0x0EC TIM8_BRK                        */
	0,                               /* 0x0F0 TIM8_UP                         */
	0,                               /* 0x0F4 TIM8_TRG_COM                    */
	0,                               /* 0x0F8 TIM8_CC                         */
	0,                               /* 0x0FC ADC3                            */
	0,                               /* 0x100 FSMC                            */
	0,                               /* 0x104 SDIO                            */
	0,                               /* 0x108 TIM5                            */
	0,                               /* 0x10C SPI3                            */
	0,                               /* 0x110 USART4                          */
	0,                               /* 0x114 USART5                          */
	0,                               /* 0x118 TIM6                            */
	0,                               /* 0x11C TIM7                            */
	0,                               /* 0x120 DMA2_Ch1                        */
	0,                               /* 0x124 DMA2_Ch2                        */
	0,                               /* 0x128 DMA2_Ch3                        */
	0,                               /* 0x12C DMA2_Ch4                        */
};

// HEAP
static char base_heap[MAX_HEAP_SIZE];
static char *heap = base_heap;

void copy_data();
void __libc_init_array();

void reset_handler() {
    copy_data();
	__libc_init_array();
    main();
    while(1);
}

__WEAK int main() {
    //EMPTY
}

__WEAK void tim3_handler() {
    //EMPTY
}

void copy_data()
{	
	char *src = &_etext;
	char *dst = &_sdata;

	// ROM has data at end of text; copy it
	while (dst < &_edata) *dst++ = *src++;

	// Zero bss
	for (dst = &_sbss; dst< &_ebss; dst++) *dst = 0;
}

caddr_t _sbrk(int incr) 
{
	char *prev_heap;
  
  	prev_heap = heap;

	if ((heap + incr) > base_heap + MAX_HEAP_SIZE) 
	{
		errno = ENOMEM;
		return (caddr_t) -1;
	}
  
  heap += incr;

  return (caddr_t) prev_heap;
}

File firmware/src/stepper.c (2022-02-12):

#include "stepper.h"

const gpio_value_t half_step[8][4] = {
    {LOW, LOW, LOW, HIGH},
    {LOW, LOW, HIGH, HIGH},
    {LOW, LOW, HIGH, LOW},
    {LOW, HIGH, HIGH, LOW},
    {LOW, HIGH, LOW, LOW},
    {HIGH, HIGH, LOW, LOW},
    {HIGH, LOW, LOW, LOW},
    {HIGH, LOW, LOW, HIGH}
};

void stepper_setup(stepper_t *stepper, GPIO_TypeDef *gpio_ports[4],
    uint32_t gpio_pins[4]) 
{
    memcpy(stepper->gpio_ports, gpio_ports, 4*sizeof(GPIO_TypeDef *));
    memcpy(stepper->gpio_pins, gpio_pins, 4*sizeof(uint32_t));

    for(int i = 0; i < 4; i++) {
        gpio_setup(gpio_ports[i], GPIO_OUT, gpio_pins[i]);
        gpio_write(gpio_ports[i], gpio_pins[i], LOW);
    }
}

void stepper_step(stepper_t *stepper, int steps)
{
    stepper->steps += steps;
}

bool stepper_is_idle(stepper_t *stepper)
{
    return (stepper->steps == 0);
}

void stepper_off(stepper_t *stepper)
{
    stepper->steps = 0;

    for(int i = 0; i < 4; i++) {
        gpio_write(stepper->gpio_ports[i], stepper->gpio_pins[i], LOW);
    }
}

void stepper_update(stepper_t *stepper)
{
    int *steps = &stepper->steps;
    int *index = &stepper->index;

    if(*steps > 0) {
        (*steps)--;
        (*index)--;
        if(*index < 0) (*index) = 7; 

    } else if(*steps < 0) {
        (*steps)++;
        (*index)++;
        if(*index > 7) *index = 0;
    } else {
        return;
    }

    for(int j = 0; j < 4; j++) {
        gpio_write(stepper->gpio_ports[j], stepper->gpio_pins[j],
            half_step[*index][j]);
    }
}

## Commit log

2022-02-09 printed version
    [arruela.stl, gears.scad, robot-wrist-mini.scad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]
2022-02-09 clean up
    [robot-wrist-mini.scad, robot-wrist-mini.stl, robot-wrist.scad]
2022-02-11 printf working
2022-02-11 adc working
2022-02-12 stepper working
2022-02-12 Proteus Schematic Update
2022-02-12 both steppers working with timer
2022-02-13 openscad documentation
    [robot-wrist.scad, robot-wrist.stl, whasher.stl]
